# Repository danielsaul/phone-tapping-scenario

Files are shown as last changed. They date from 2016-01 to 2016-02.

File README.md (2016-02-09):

# phone-tapping-scenario
Scenario Y, 2nd Year UCL EEE, Phone Line Tapping Scenario
January 2016

## Design Brief
A small company that is using an external switchboard for its phone exchange would like to monitor their employees phone usage. For that purpose you have been hired to setup an apparatus (hardware and software) to be non destructively attached to the phone line that would be able to give as an output the phone number called. The phone used by the company gives a standard dual tone multi-frequency (DTMF) dialling system and the phone line would also carry the internet ADSL and other signals.

## Overview
The solution consists of two main stages: analogue filtering of the acquired signal and then digital processing of the filtered signal.
The signal is picked up by coiling a wire around a length of the telephone cable without cutting the line, this is fed through several stages of analogue filters to remove unwanted noise and signals such as 50Hz mains and ADSL. The filtered signal is then passed into an analog-to-digital converter (ADC) in a microcontroller before being digitally processed to find which frequencies are present. From these, the DTMF tones being dialled can be ascertained. Two versions of the digital section have been developed, one to run entirely on an MSP430 microcontroller and one where the ADC values are sent over serial to a python program, which can then automatically call the number.

## Analogue Section
The signal acquired from the phone line will have the required DTMF tones lying in the frequency range 697Hz - 1477Hz. The signal could also contain ADSL which will be >25kHz and the rudimentary antenna will likely pick up a lot of noise. Therefore the analogue section consists of several stages:

1. Simple buffer stage for impedance matching
2. 4th Order High Pass Filter - removes low frequency noise, particularly 50Hz
3. 4th Order Low Pass Filter - removes high frequencies, particularly ADSL
4. Gain Stage (Inverting Amplifier)
5. DC Biasing for input to ADC

Multisim circuits for the above can be found in the relevant directory.

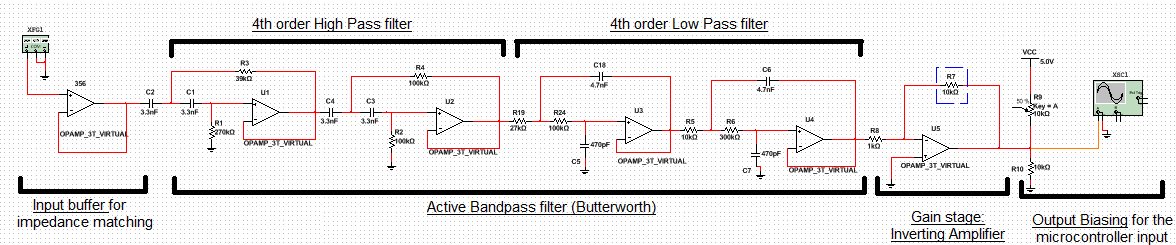
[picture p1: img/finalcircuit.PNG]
analogue section Analogue Section Circuit


## Digital Processing
Both versions of the digital section are based on the same principles. The signal is passed into an ADC and processed in real-time at a certain sample rate, using the Goertzel Algorithm configured to find the the DTMF frequencies: [697Hz, 770Hz, 852Hz, 941Hz] and [1209Hz, 1336Hz, 1477Hz]. The Goertzel algorithm allows us to detect tones more efficiently, with far less horsepower than the Fast Fourier Transform for example. The theory behind the algorithm can be easily found through a search and so it won't be repeated here, but it is essentially a series of bandpass infinite impulse response (IIR) filters at the relevant frequencies.

Once the Goertzel algorithm has returned a magnitude for each frequency after N samples, they are compared against a threshold value to determine if the frequencies are present. The most likely frequency, with the highest magnitude, for each group is taken and then the relevant digit looked up and saved:

| | 1209Hz | 1336Hz | 1477Hz |
|:---|:---:|:---:|:---:|
| **697Hz** | 1 | 2 | 3 |
| **770Hz** | 4 | 5 | 6 |
| **852Hz** | 7 | 8 | 9 |
| **941Hz** | * | 0 | # |

The C version is written to be run on an isolated MSP430 with the decoded number displayed on an LCD. A timer is configured to trigger an interrupt at a specific interval to get a certain sampling frequency, 4kHz was found to be high enough to be able to detect our highest frequencies without any issues whilst leaving enough time between samples for processing. The 10bit ADC is triggered at this sample rate and then the resolution of the result reduced to 8bit to reduce the processing time required.

The Python version has been written to be able to process pre-recorded data files or real-time data from a serial port. A crude Arduino sketch has been written to read the signal at 4kHz using it's ADC and then write the resulting value to the connected computer over a serial port. The Python script will then process the signal in real-time before displaying the decoded number. It can then also use the Twilio API to automatically call or send an SMS to the number within seconds of decoding - useful in winning competitions...

## Authors
- Daniel Saul
- Franky Saxena
- Bruno Calogero
- Theo Velon

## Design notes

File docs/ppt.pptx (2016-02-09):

## Scenario W: Phone Tapping Scenario Bruno Calogero Daniel Saul Franky Saxena Theo Velon

Context and Overall System Diagram


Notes: Explain overall context and what we are trying to achieve , add flowchart ?

## Extracting the signal (Coil and buffer stage)

- Coiling the wire (twisted-parallel as by Faraday’s Law)
- Impedance matching using a high input impedance Buffer (MOSFET 365 OP-AMP)

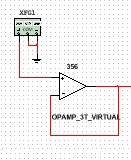
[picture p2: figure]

Fig. 2 Buffer

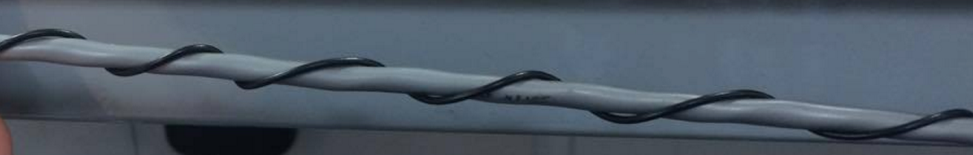
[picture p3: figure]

Fig.1 Parallel wiring to internal cabling

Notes: Coiling the wire – explain the black box way + antenna hence no grounding + need or impedance matching + only presence of AC signals

## Band-pass filtering

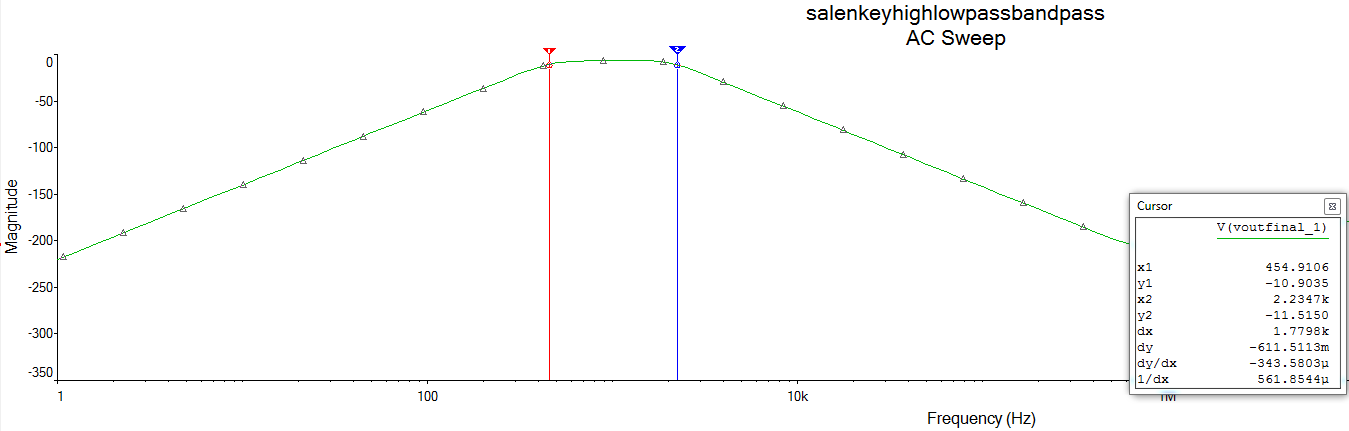
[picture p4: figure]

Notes: Oscilloscope output + bode plot + system diagram with only bandpass (2nd order highpass +2nd order lowpass )

## Gain/DC Bias/ADC

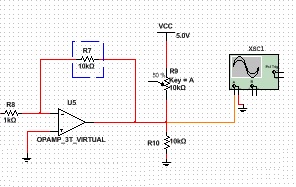
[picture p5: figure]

- Inverting amplifier stage
- DC Bias stage
- All selected suitably for the Microprocessor

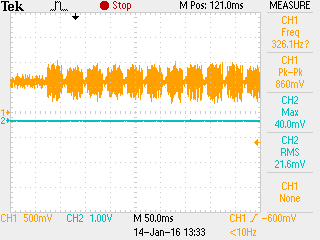
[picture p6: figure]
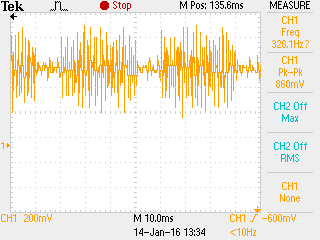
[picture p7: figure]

## Goertzel Algorithm (Digital Signal Processing and API)

- Data → Serial
- Sample rate = 4000Hz, high enough for accurate sampling but low enough so data can be read and sent to DTMF function
- Acquiring bin width = Fs / N
- Threshold = magnitude threshold
- Goertzel function:
  - Compute coefficients
  - Calculate magnitude for each frequency
  - DTMF function:
    - Finding the max magnitude and goes through each row frequency and column frequency to identify the number
    - Outputs the 11 digit number, setting the threshold against the noise (to get rid of background noise)

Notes: Coupling/Decoupling capacitors at the rail voltages to get rid of the noise from the powersupply/oscilloscope

## Conclusion

- Problems encountered : - Decoupling capacitor to reduce rail noise - Coding implementation
- Final phone number retrieved

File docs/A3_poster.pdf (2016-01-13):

name
Op-Amp | LM741
Resistors (kΩ) | 180, 18, 47,56,27,220,150,39,270,220
Capacitors | 2.2uF, 2.2nF, 4 x 470pF, 2 x 3.3nF
Wire | Single core copper wire for coil antenna

Problems
- When you coil the wire, one end goes to the input of the buffer for impedance matching, however the output of the buffer is distorting the signal
- Solution: using the bandpass filter it will get rid of all the noise frequencies
- DC Biasing needs to be accurate
- Solution: test with POT with the correct signal on oscilloscope.
- Not having correct value components and tolerances.
- Solution: Work with parallel/serial configurations to get the most accurate value possible.

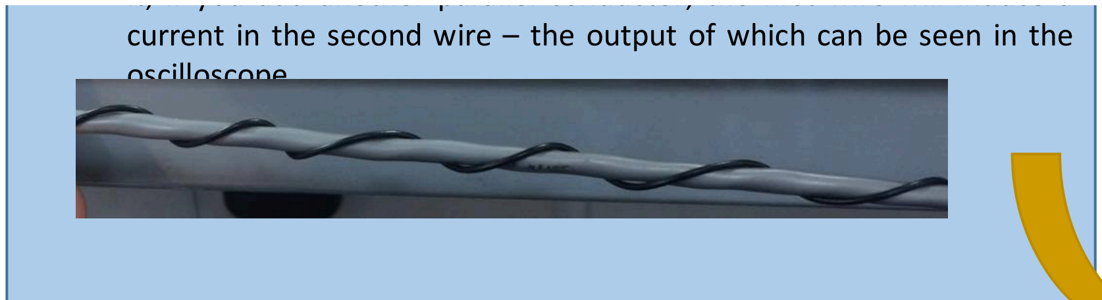
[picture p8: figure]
oscilloscope.

current in the second wire – the output of which can be seen in the

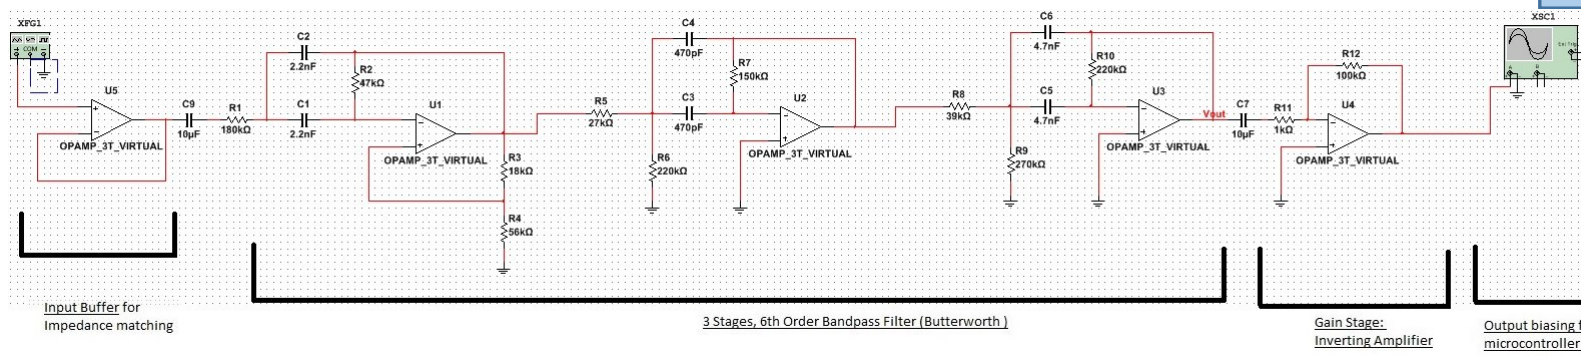
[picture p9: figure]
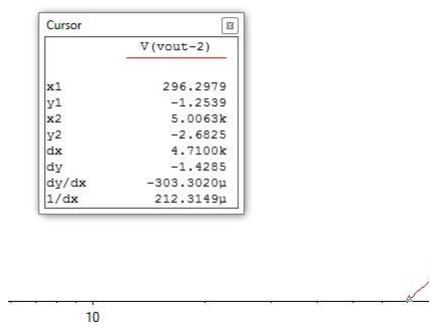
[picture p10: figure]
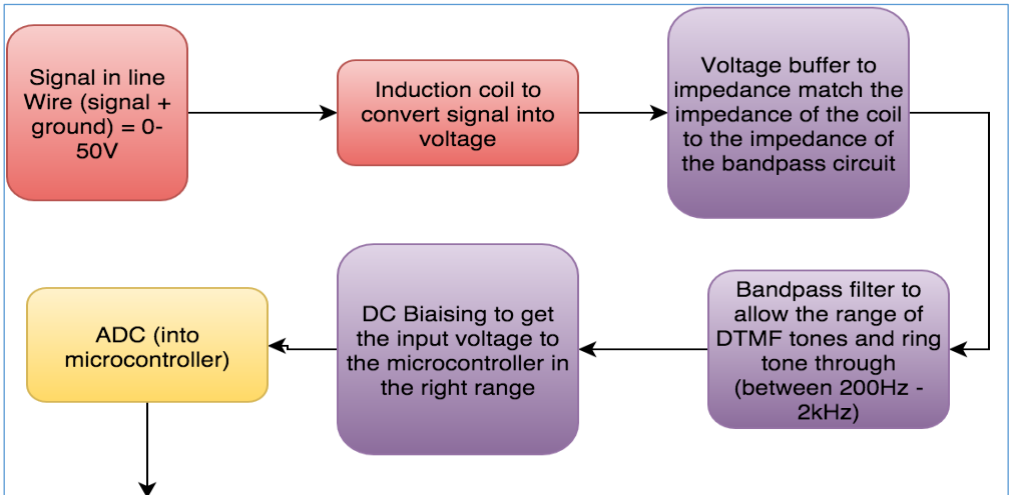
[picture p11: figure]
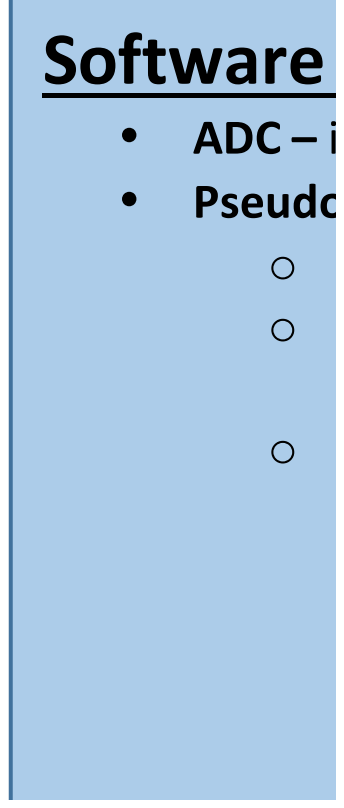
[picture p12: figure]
• Pseudocode:

Software • ADC – in order to compute digitally all the analog signals

- nums = { {1, 2, 3}, {4,5,6}, {7,8,9} }
- for each frequency:
- 8kHz interrupt loop:

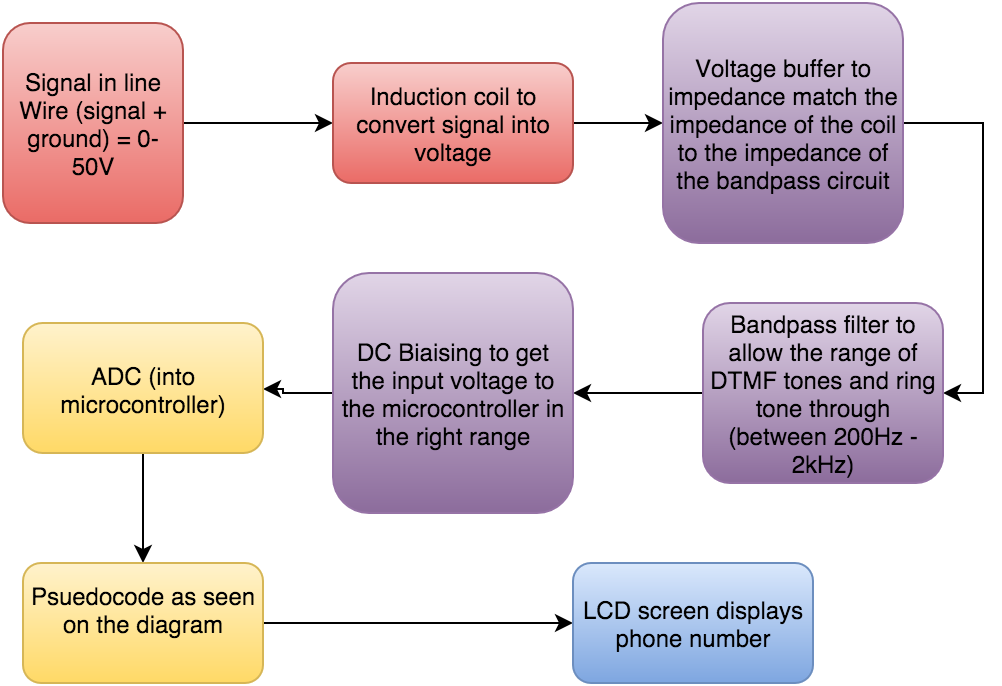
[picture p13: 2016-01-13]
img/System_diagramforposter.png

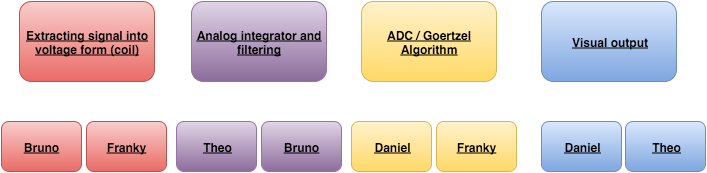
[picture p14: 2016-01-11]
img/subsystem_subteam.png

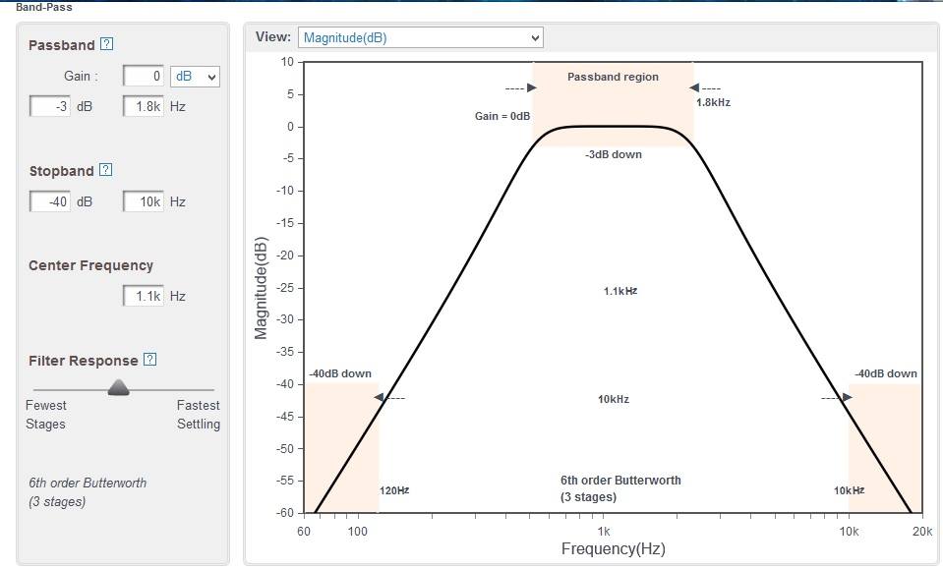
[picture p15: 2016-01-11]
img/bandpass_filter.jpg

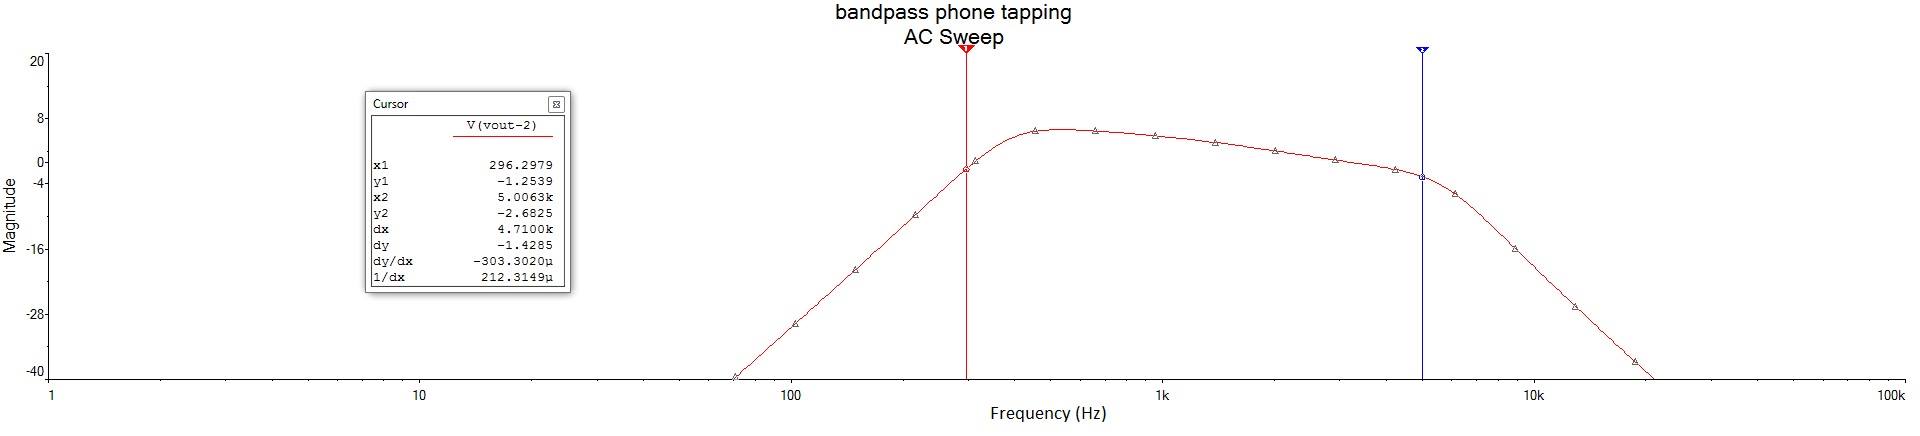
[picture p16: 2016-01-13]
img/bodeplotofentirecircuit.jpg

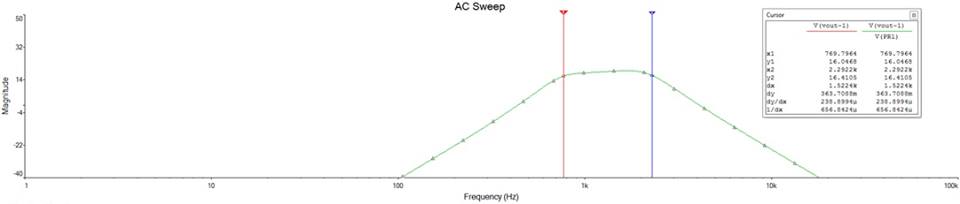
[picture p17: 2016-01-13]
img/bandpassgraphnew.jpg

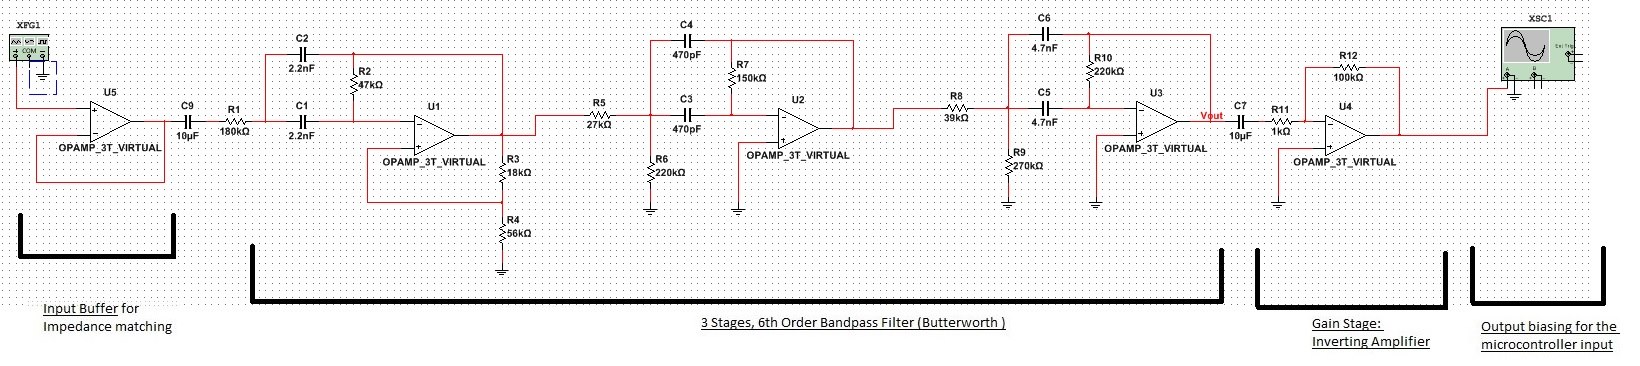
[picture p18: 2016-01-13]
img/newbp.jpg

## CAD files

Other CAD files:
autocad/plastic_core.dwg

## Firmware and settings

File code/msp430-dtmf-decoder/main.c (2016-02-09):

/*
 * Phone Tapping Scenario
 * DTMF Decoder
 * MSP430G2553
 * Daniel Saul, 2016
 *
 * main.c
 *
 */

#include <msp430g2553.h>
#include <math.h>
#include <stdbool.h>
#include "main.h"
#include "LCDDisplay.h"

// Timing Loop
#pragma vector=TIMER0_A0_VECTOR
__interrupt void Timer_A(void)
{
  flag = 1;
  return;
}

int main(void){

  WDTCTL = WDTPW + WDTHOLD;
  BCSCTL1 = CALBC1_16MHZ;
  DCOCTL = CALDCO_16MHZ;

  // P1.0 timing loop pulse
  P1DIR |= BIT0;
  P1OUT &= ~BIT0;

  // LCD Config
  LCDConfigure();
  LCDBackLight(300);
  LCDHome();
  LCDCursorOff();
  LCDBlinkOff();
  LCDClear();

  // ADC Config
  ADC10CTL0 = SREF_0 | ADC10SHT_0 | ADC10ON; // 3.3V ref
  ADC10CTL1 = INCH_4 | ADC10DIV_0; // ADC channel 4,
  ADC10AE0 = BIT4; // P1.4
  ADC10CTL0 |= ENC;

  // Generate coeffs
  for(i=0; i<4; i++){     // Rows
    int k = (int)(0.5 + ((NUM*rows[i])/fs));
    long x = (long)(256 * (2 * cos((2*PI*k)/NUM)));
    row_coeffs[i] = x;
  }
  for(i=0; i<3; i++){     // Cols
    int k = (int)(0.5 + ((NUM*cols[i])/fs));
    long x = (long)(256 * (2 * cos((2*PI*k)/NUM)));
    col_coeffs[i] = x;
  }

  // Timer A Config
  TACCTL0 |= CCIE;
  TACCR0 = 500-1;	// 4kHz
  TACTL |= TASSEL_2 + ID_3; // SMCLK & clk/8
  TACTL |= MC_1;	//Use UP mode timer


  while(1){

    // Flag is enabled at sampling rate
    if(!flag){
      continue;
    }
    flag = 0;


    ADC10CTL0 |= ADC10SC; // Trigger ADC Conversion
    while( ADC10CTL1 & ADC10BUSY ) ;
    int adcvalue = (long)ADC10MEM / 4; // Divide into 8bit

    // Requires x samples of no signal before capturing next tone
    // 400 samples of no signal means new phone number entirely
    if(!newtone){
      if(adcvalue > signal_lower_threshold && adcvalue < signal_upper_threshold){
        cnt++;
      }else{
        if(cnt > 10){
          newtone = true;
        }
        if(cnt > 400){
          m = 0;
        }
        cnt = 0;
      }
    }

    if(newtone){

      P1OUT |= BIT0; // P1.0 High - Start of 8kHz loop

      update_goertzel(adcvalue);

      n++; // Increment sample counter

      if(n == NUM){ // If enough samples
        n=0; // Reset sample counter

        char a = calculate_goertzel_magnitudes(); // Calculate magnitudes

        if(a){ // Must be both a row and col above the threshold

          int col = determineCol();
          int row = determineRow();

          char result = nums[row][col];
          number[m] = result;

          m++;
          if(m > 10){
            // Entire phone number decoded, write to LCD
            m = 0;
            LCDClear();
            LCDHome();
            LCDWriteString(number);

          }

        }

        newtone = false;

      }

    }

    P1OUT &= ~BIT0; // P1.0 Low - End of 8kHz loop
  }

}

int determineCol(void){

  if(magc[0] > magc[1] && magc[0] > magc[2]){
    return 0;
  }
  if(magc[1] > magc[0] && magc[1] > magc[2]){
    return 1;
  }
  return 2;

}

int determineRow(void){

  if(magr[0] > magr[1] && magr[0] > magr[2] && magr[0] > magr[3]){
    return 0;
  }
  if(magr[1] > magr[0] && magr[1] > magr[2] && magr[1] > magr[3]){
    return 1;
  }
  if(magr[2] > magr[0] && magr[2] > magr[1] && magr[2] > magr[3]){
    return 2;
  }
  return 3;

}

char calculate_goertzel_magnitudes(void){

  char aboveThreshold = 0;

  //Magnitude Rows
  for(i=0; i<4; i++){

    magr[i] = (((long)Qr[i][1] * (long)Qr[i][1]) + ((long)Qr[i][2] * (long)Qr[i][2]) - (((long)row_coeffs[i] * (long)Qr[i][1] * (long)Qr[i][2])/256));

    Qr[i][1] = 0;
    Qr[i][2] = 0;

    if(magr[i] > threshold){
      aboveThreshold = 1;
    }

  }

  if(!aboveThreshold){
    return 0;
  }

  aboveThreshold = 0;

  //Magnitude Cols
  for(i=0; i<3; i++){

    magc[i] = (((long)Qc[i][1] * (long)Qc[i][1]) + ((long)Qc[i][2] * (long)Qc[i][2]) - (((long)col_coeffs[i] * (long)Qc[i][1] * (long)Qc[i][2])/256));

    Qc[i][1] = 0;
    Qc[i][2] = 0;

    if(magc[i] > threshold){
      aboveThreshold = 1;
    }
  }

  if(!aboveThreshold){
    return 0;
  }

  return 1;

}

void update_goertzel(int val){

  //Rows
  for(i=0; i<4; i++){
    Qr[i][0] = (((long)row_coeffs[i] * (long)Qr[i][1])/256);
    Qr[i][0] -= Qr[i][2];
    Qr[i][0] += val;
    Qr[i][2] = Qr[i][1];
    Qr[i][1] = Qr[i][0];
  }

  //Cols
  for(i=0; i<3; i++){
    Qc[i][0] = (((long)col_coeffs[i] * (long)Qc[i][1])/256);
    Qc[i][0] -= Qc[i][2];
    Qc[i][0] += val;
    Qc[i][2] = Qc[i][1];
    Qc[i][1] = Qc[i][0];
  }

}

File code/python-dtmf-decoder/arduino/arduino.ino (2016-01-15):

#include <TimerOne.h>


int value = 0;
volatile int flag = 0;
void setup() {
  // set prescale to 16
bitClear(ADCSRA,ADPS0); 
bitSet(ADCSRA,ADPS1); 
bitClear(ADCSRA,ADPS2);

  Serial.begin(921600); 
  pinMode(2, OUTPUT);  
  Serial.println("setup");
  delay(100);
  
  Timer1.initialize(250);
  Timer1.attachInterrupt(timerIsr);

}

void loop() {


}

void timerIsr()
{
    value = analogRead(A0);
      Serial.println(value);
}

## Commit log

2016-01-11 added system flowchart
2016-01-11 added bandpass filter multisim
2016-01-12 added plastic core
    [plastic_core.dwg]
2016-01-14 Needs 3 samples of no signal betweene each tone
2016-01-14 final response circuit
2016-01-14 added final circuit diagram and bode plot
2016-01-14 added sub circuit diagrams
2016-01-14 Tracks signal, wrong number output
    [main.c]
2016-01-15 powerpoint presentation
